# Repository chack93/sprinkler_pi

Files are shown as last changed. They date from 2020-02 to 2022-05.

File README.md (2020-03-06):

# sprinkler_pi

Raspberry Pi controlled plant sprinkler.

## files

### sprinkler_pi

contains pump & sensor controller.

### sprinkler_pi_ui

is a phoenix server providing a website to control the sprinkler system.

### hardware

contains the kicad project of the used circuit.
led's, manual override button & water level sensor are supplied by the raspberry (3.3V).  
pump & solenoid powered valve need to be powered by an external 12V power supply. the power supply need to be powerful enought to support both water pump & solenoid, as well as momentary inrush current on power on.  
most water pump can't pump air well, therefore a solenoid valve is attached right after the pump output to stop backflow. the valve need to be normally closed for this to work.

## building
```
cd sprinkler_pi

# specify raspberry model (raspberry zero in this case)
export MIX_TARGET=rpi0

# setup wifi to connect to
export NERVES_NETWORK_KEY_MGMT=WPA-PSK
export NERVES_NETWORK_SSID=INSERT_WIFI
export NERVES_NETWORK_PSK=INSERT_WIFI_PW

# fetch dependencies
mix deps.get

# generate secret key base for phoenix
mix phx.gen.secret
# copy & paste generated secret
export SECRET_KEY_BASE=INSERT_SKB

# generate image & burn on attached sd-card
MIX_ENV=prod mix firmware.burn
```

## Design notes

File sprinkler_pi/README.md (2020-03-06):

# SprinklerPi

Raspberry Pi controlled plant sprinkler

## create firmware

### set environment variable

```
# specify raspberry model
export MIX_TARGET=rpi0

# setup wifi to connect to
export NERVES_NETWORK_KEY_MGMT=WPA-PSK
export NERVES_NETWORK_SSID=INSERT_WIFI
export NERVES_NETWORK_PSK=INSERT_WIFI_PW

# generate secret key base for phoenix
export SECRET_KEY_BASE=INSERT_SKB
```

### create firmware sd card

```
MIX_ENV=prod mix firmware.burn
```

### update firmware remotely

```
MIX_ENV=prod mix firmware
MIX_ENV=prod ./upload.sh sprinkler_pi.local
```

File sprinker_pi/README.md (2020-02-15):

# SprinkerPi

Raspberry Pi controlled plant sprinkler

## Getting Started

To start your Nerves app:
  * `export MIX_TARGET=my_target` or prefix every command with
    `MIX_TARGET=my_target`. For example, `MIX_TARGET=rpi0`
  * Install dependencies with `mix deps.get`
  * Create firmware with `mix firmware`
  * Burn to an SD card with `mix firmware.burn`

## Create firmware sd card

export MIX_TARGET=rpi0
mix firmware.burn

## Targets

Nerves applications produce images for hardware targets based on the
`MIX_TARGET` environment variable. If `MIX_TARGET` is unset, `mix` builds an
image that runs on the host (e.g., your laptop). This is useful for executing
logic tests, running utilities, and debugging. Other targets are represented by
a short name like `rpi3` that maps to a Nerves system image for that platform.
All of this logic is in the generated `mix.exs` and may be customized. For more
information about targets see:

https://hexdocs.pm/nerves/targets.html#content

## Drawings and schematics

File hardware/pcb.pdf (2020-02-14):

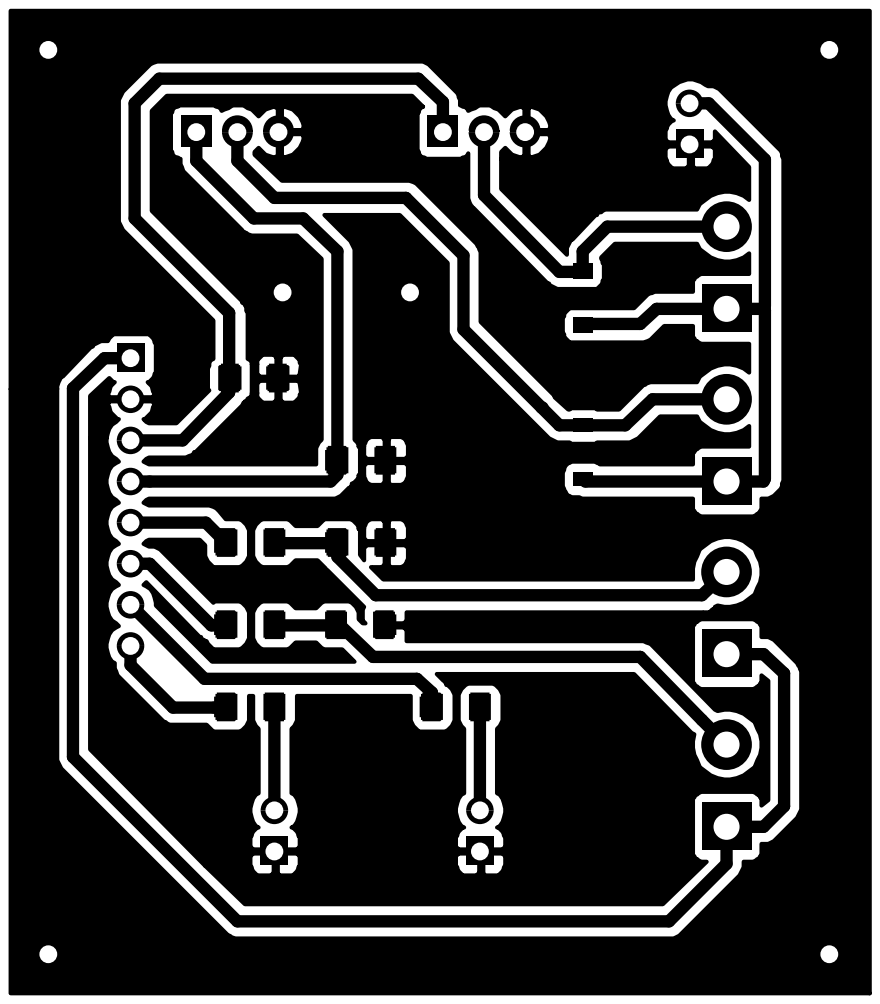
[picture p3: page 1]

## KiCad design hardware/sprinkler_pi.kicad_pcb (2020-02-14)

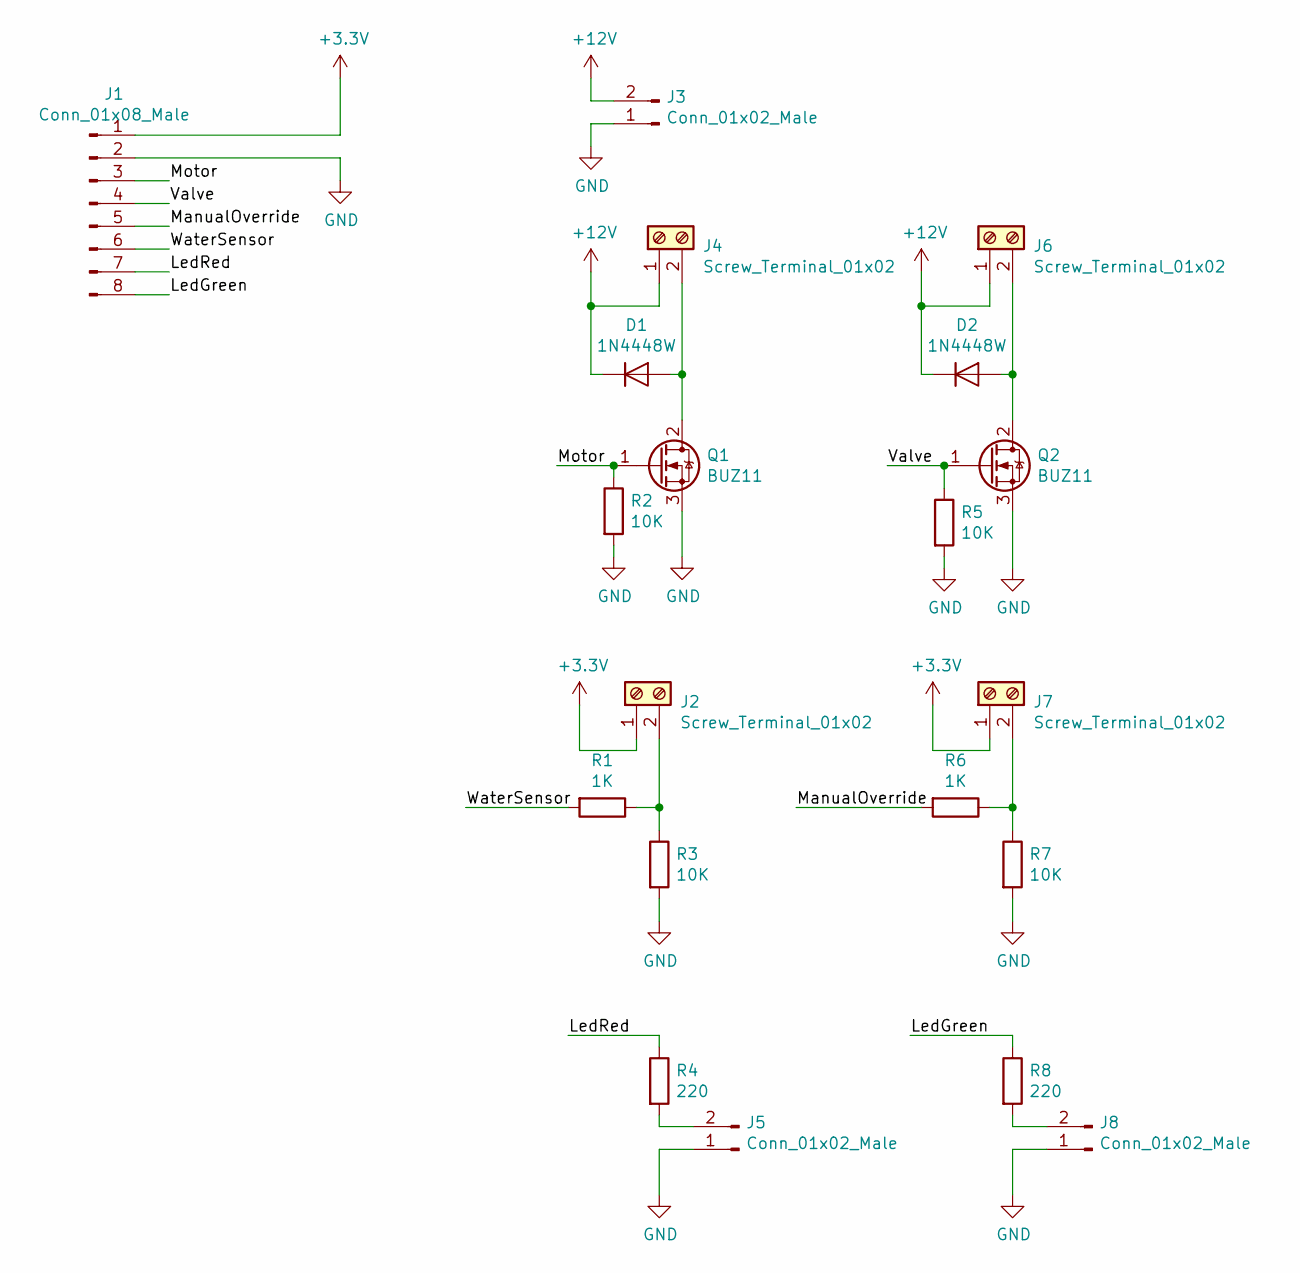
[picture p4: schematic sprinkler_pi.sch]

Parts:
D1, D2: 1N4448W; D_SOD-123
J1: Conn_01x08_Male; PinHeader_1x08_P2.54mm_Vertical
J2, J4, J6, J7: Screw_Terminal_01x02; TerminalBlock_bornier-2_P5.08mm
J3, J5, J8: Conn_01x02_Male; PinHeader_1x02_P2.54mm_Vertical
Q1, Q2: BUZ11; TO-220-3_Vertical
R1, R6: 1K; R_1206_3216Metric_Pad1.42x1.75mm_HandSolder
R2, R3, R5, R7: 10K; R_1206_3216Metric_Pad1.42x1.75mm_HandSolder
R4, R8: 220; R_1206_3216Metric_Pad1.42x1.75mm_HandSolder

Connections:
+3V3: J1.1, J2.1, J7.1
+12V: D1.1 (K), D2.1 (K), J3.2, J4.1, J6.1
/LedGreen: J1.8, R8.1
/LedRed: J1.7, R4.1
/ManualOverride: J1.5, R6.2
/Motor: J1.3, Q1.1 (G), R2.1
/Valve: J1.4, Q2.1 (G), R5.1
/WaterSensor: J1.6, R1.2
GND: J1.2, J3.1, J5.1, J8.1, Q1.3 (S), Q2.3 (S), R2.2, R3.2, R5.2, R7.2
unnamed: D1.2 (A), J4.2, Q1.2 (D)
unnamed: D2.2 (A), J6.2, Q2.2 (D)
unnamed: J2.2, R1.1, R3.1
unnamed: J5.2, R4.2
unnamed: J7.2, R6.1, R7.1
unnamed: J8.2, R8.2

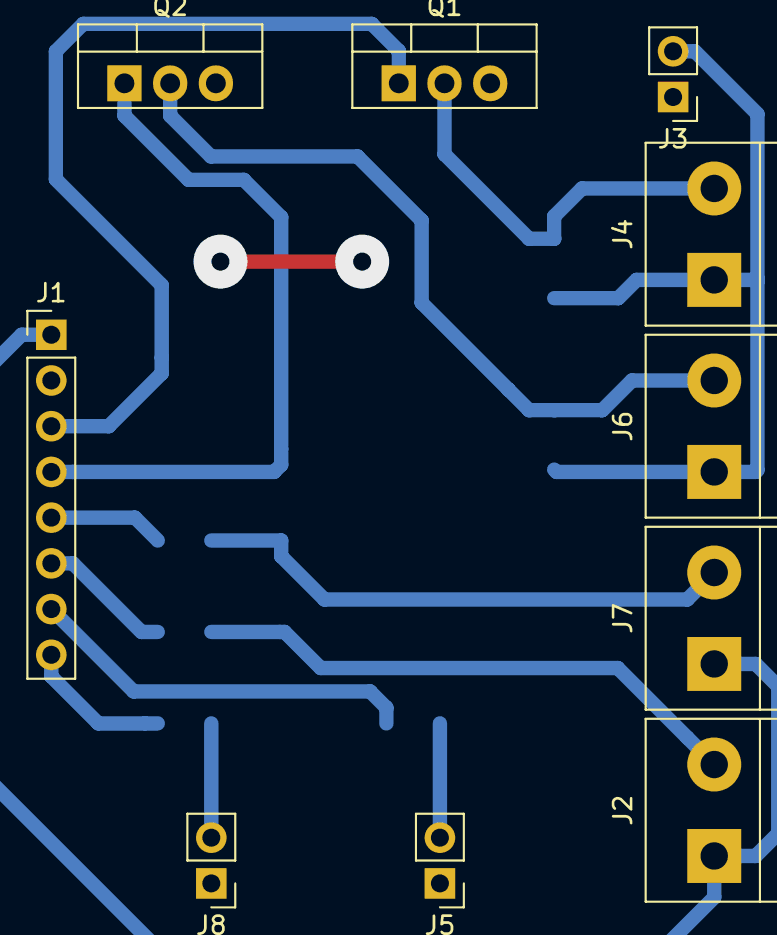
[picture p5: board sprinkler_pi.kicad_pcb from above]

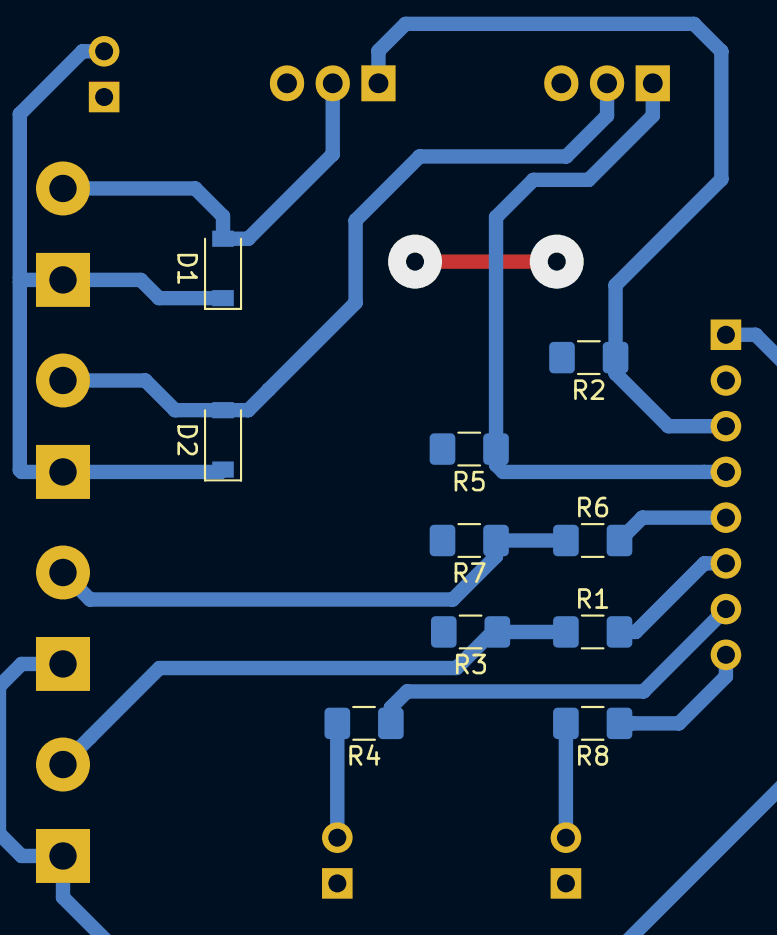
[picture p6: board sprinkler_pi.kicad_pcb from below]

Board: 2 copper layers, 20 parts (10 on the bottom side), 15 nets.

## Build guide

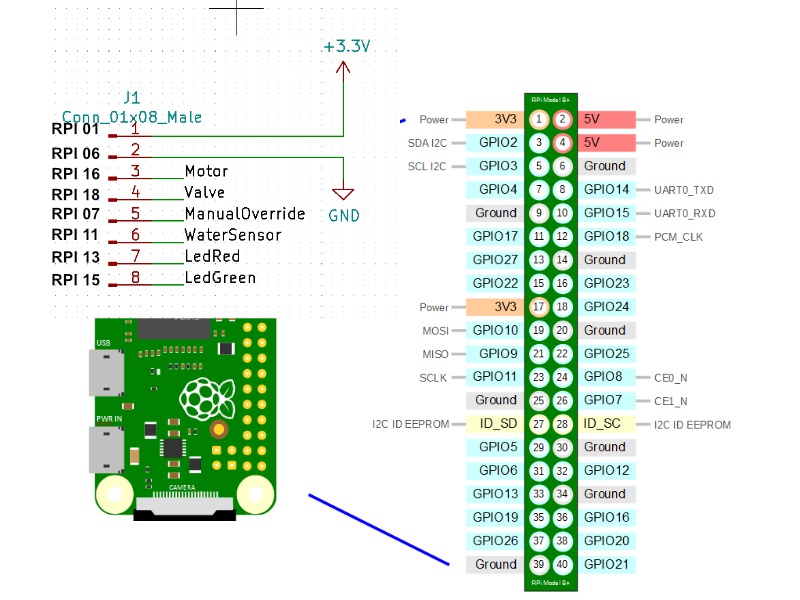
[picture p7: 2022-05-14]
hardware/wiring.png

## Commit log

2020-02-14 add controller board hardware schematic & pcb design
    [sprinkler_pi.kicad_pcb, sprinkler_pi.sch]
2020-02-17 add easy access functions to Control.ex fix pin assignment
2020-03-01 add schedule & pump control
2020-03-07 add manual override button handler
2022-05-14 add .env to gitignore
    [sprinkler_pi-B_Cu.gbr, sprinkler_pi-Edge_Cuts.gbr]
